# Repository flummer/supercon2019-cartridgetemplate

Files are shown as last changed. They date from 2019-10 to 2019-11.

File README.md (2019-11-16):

# Unofficial KiCad template for a 2019 Hackaday Superconference Badge Cartridge

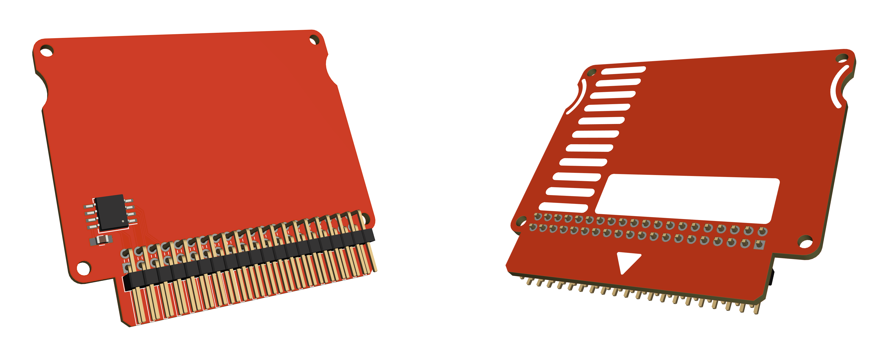
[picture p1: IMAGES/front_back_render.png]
Cartridge template render


This template can be used as a starting point to make a cartridge for the Supercon badge, that will mate with the 40 pin expansion connector on the back of the badge.

| WARNING: This design is unofficial, and has NOT been tested |
| --- |

It's using an angled 2x20 pin male header, a w25q128 SPI flash and a 100nF cap. The schematic has the pins named using global nets, so it's easy to simply add in your own stuff.

## Version 1.2 update

This updated version fixes an error in the pin connections on the cartridge connector (the two columns was flipped for some signals) and adds a copper pour (connected to GND) on the bottom layer too.

## Special note about the original version

If you want to use a PCB based on the original version with incorrect connections, it is possible to make a hardware hack on the 20x2 angeled header, where you move the pins around and bend some of them a bit, very precisely.

## License

The contents of this repository is released under the following licence:

 * the "Creative Commons Attribution-ShareAlike 4.0 International License"
   (CC BY-SA 4.0) full text of this license is included in the LICENSE file
   and a copy can also be found at
   http://creativecommons.org/licenses/by-sa/4.0/

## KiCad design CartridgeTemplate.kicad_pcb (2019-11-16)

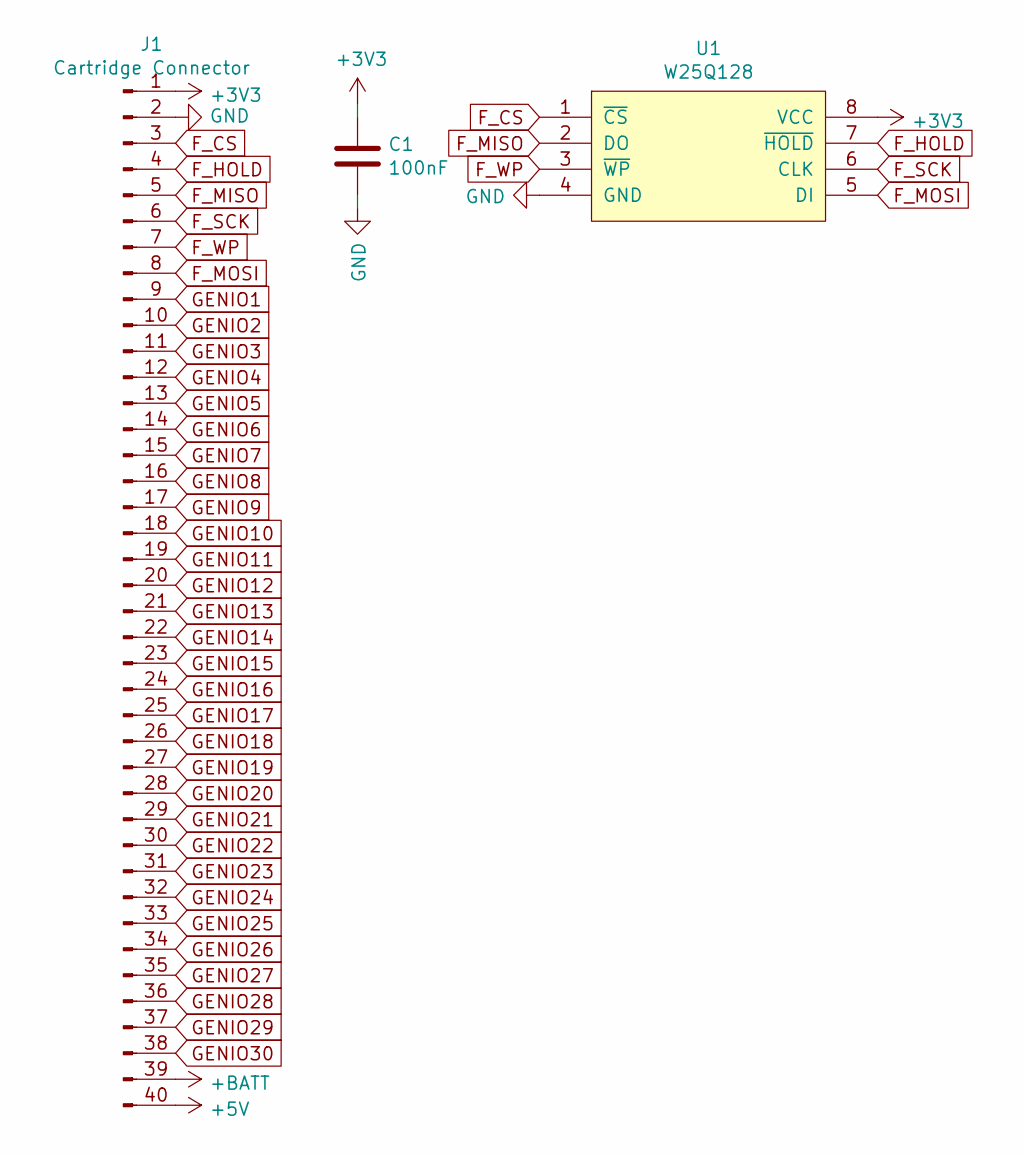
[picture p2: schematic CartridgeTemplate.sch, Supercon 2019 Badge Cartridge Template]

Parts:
C1: 100nF; C_0805_HandSoldering
J1: Cartridge Connector; Supercon_Cartridge_40pin_Connector
U1: W25Q128; SO-8_5.3x6.2mm_Pitch1.27mm

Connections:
+3V3: C1.1, J1.1, U1.8 (VCC)
+5V: J1.40
+BATT: J1.39
F_CS: J1.3, U1.1 (~CS)
F_HOLD: J1.4, U1.7 (~HOLD)
F_MISO: J1.5, U1.2 (DO)
F_MOSI: J1.8, U1.5 (DI)
F_SCK: J1.6, U1.6 (CLK)
F_WP: J1.7, U1.3 (~WP)
GENIO1: J1.9
GENIO2: J1.10
GENIO3: J1.11
GENIO4: J1.12
GENIO5: J1.13
GENIO6: J1.14
GENIO7: J1.15
GENIO8: J1.16
GENIO9: J1.17
GENIO10: J1.18
GENIO11: J1.19
GENIO12: J1.20
GENIO13: J1.21
GENIO14: J1.22
GENIO15: J1.23
GENIO16: J1.24
GENIO17: J1.25
GENIO18: J1.26
GENIO19: J1.27
GENIO20: J1.28
GENIO21: J1.29
GENIO22: J1.30
GENIO23: J1.31
GENIO24: J1.32
GENIO25: J1.33
GENIO26: J1.34
GENIO27: J1.35
GENIO28: J1.36
GENIO29: J1.37
GENIO30: J1.38
GND: C1.2, J1.2, U1.4 (GND)

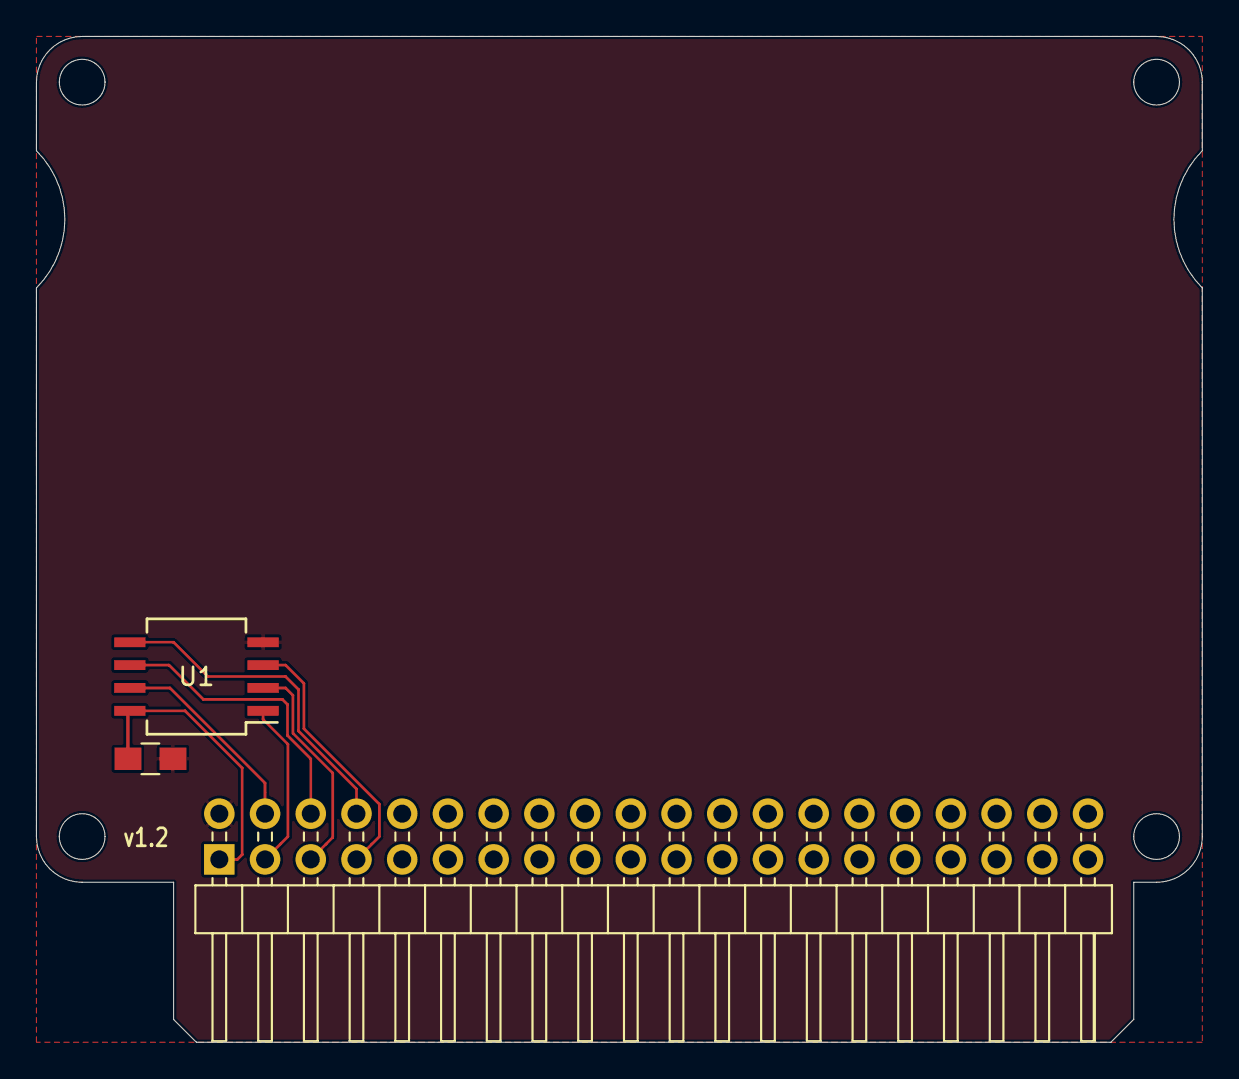
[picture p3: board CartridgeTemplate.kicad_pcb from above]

Board: 2 copper layers, 64.8 x 55.9 mm, 3 parts (0 on the bottom side), 8 nets.

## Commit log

2019-10-08 Initial commit
    Initial version of the template, should work, but has NOT been tested with actual hardware
    [CartridgeTemplate.kicad_pcb, CartridgeTemplate.sch]
2019-10-16 Added badge outline in Dwgs.Use
    This is not the exact outline, but a guess based on the official proto breakout cartridge and a photo of a badge
    [CartridgeTemplate.kicad_pcb]
2019-10-25 Moved auxillary axis origin to make more sense
    [CartridgeTemplate.kicad_pcb]
2019-11-16 Fixed error in cartridge connector pin assignments
    Also added copper pour on bottom layer
    Updated to version 1.2
    [CartridgeTemplate.kicad_pcb, CartridgeTemplate.sch]
